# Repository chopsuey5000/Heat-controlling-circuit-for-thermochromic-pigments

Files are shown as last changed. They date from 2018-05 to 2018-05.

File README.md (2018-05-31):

# Heat-controlling-circuit-for-thermochromic-pigments

## Overview
Thermochromic inks are pigments that change color to colorless at certain temperature. There are many different types of thermochromic pigments including textile inks for textile screen printing.

You may use any heat source or your body heat to change the color of thermochromic prints. But also, we can use electricity to heat up certain parts of the fabric to achieve dynamic pattern on fabric.
When large current goes through low resistance conductive material, it emits heat. We can use this method to heat up conductive threads to change colors of the prints.

## Calculations
All conductive threads have different properties, the resistance per meter is different in all of them.
The ideal conductive threads to build a heating source are made of steel or copper.

Some __recommended conductive threads__ like Bekinox stainless steel thread from Bekaert or Copper thread from KarlGrimm.

The __best scenario would be to have a 6-50 Ohm conductive thread with a current of 300-1000 mA__ flowing through it. The time the thermochromic ink takes to change its color is directly proportional to the amount of current. For 300mA it will need more time than for 1000mA.

To __calculate the voltage__ we just need to use ohm's law formula:

Voltage equals Current times Resistance or V = I x R

We know our conductive thread resistance(measured with the multimeter), for example 32 ohm, the current has to be a value from 300mA to 1000mA.

__For 300mA:__

__V = 0,3 * 32 => V = 9,6V__

__For 1000mA:__

__V = 1 * 32 => V = 32V__

## One conductive thread test circuit

### Materials
- Arduino UNO board
- Transistor, TIP122 or IRLZ24N or IRLB8743
- Conductive thread
- Jumper wires
- Protoboard
- Variable DC power supply

### Wiring

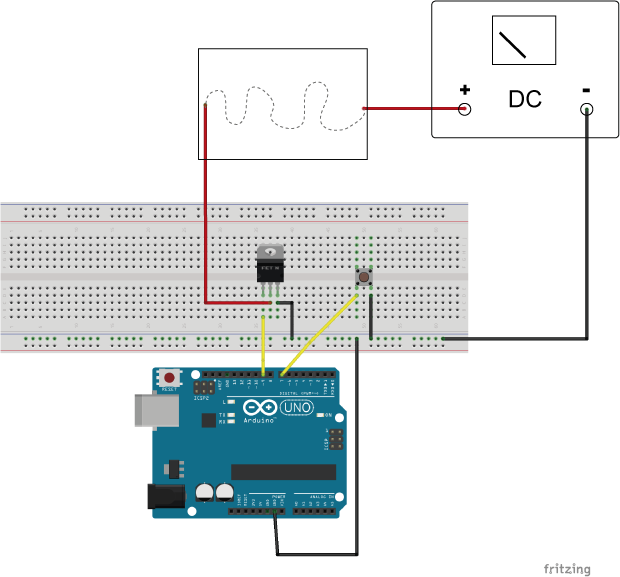
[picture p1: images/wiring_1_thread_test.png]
wiring


### Code - [view](code/_1_thread_test/)

```c++
int btnPin = 7;
int mosfetPin = 9;

void setup() {
  // put your setup code here, to run once:
  pinMode(btnPin,INPUT_PULLUP);
  pinMode(mosfetPin,OUTPUT);
  Serial.begin(9600);
}

void loop() {
  // put your main code here, to run repeatedly:
  int btnState = digitalRead(btnPin); //reads a stores button state
  if(btnState==LOW){
    //button is pressed, so START heating up the conductive thread
    digitalWrite(mosfetPin,HIGH);
  }else{
    //button is released, so STOP heating up the conductive thread
    digitalWrite(mosfetPin,LOW);
  }
}
```

## Multiple conductive threads circuit

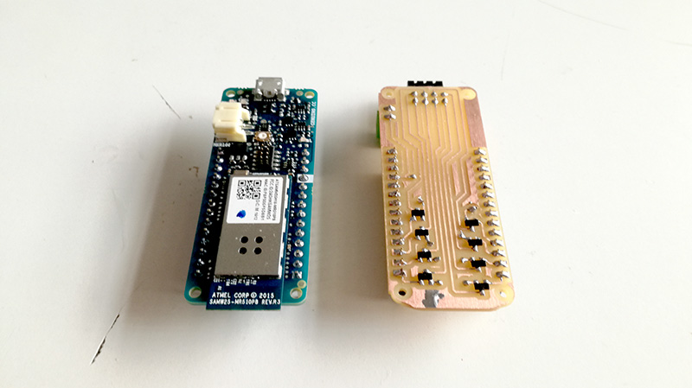
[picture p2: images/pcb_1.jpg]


### Materials
- Arduino MKR1000
- 8x Transistor BC817
- 8x Conductive thread

### PCB

[schematic & board design files](pcb/)

### Code - [view](code/_8_threads_test/)

```c++
#define numStrings 8

int actualString = 0;
int actualTime;
int intervalON = 8000;
int intervalOFF = 10000;
boolean state = 0;

const int pins[numStrings] = {
  9,8,7,6,5,4,3,2
};

const int timeON[numStrings] = {
  7000,9000,10000,10000,5000,6500,8000,10000
};

void setup() {
  // put your setup code here, to run once: 
  Serial.begin(9600);

  for(int i=0;i<numStrings;i++){
    pinMode(pins[i],OUTPUT);
  }

  actualTime = millis();
  
}

void loop() {
  // put your main code here, to run repeatedly:
  if(state==0 && millis()<(actualTime+timeON[actualString]))
  {
    int left = (actualTime+timeON[actualString])-millis();
    Serial.print("ON ");
    Serial.print(" : ");
    Serial.print(actualString);
    Serial.print(" : ");
    Serial.println(left);
    analogWrite(pins[actualString],255);
  }else if (state==0 && millis()>(actualTime+intervalON)){
    actualTime = millis();
    state=1;
  }

  if(state==1 && millis()<(actualTime+intervalOFF))
  {
    int left = (actualTime+intervalOFF)-millis();
    Serial.print("OFF ");
    Serial.print(" : ");
    Serial.print(actualString);
    Serial.print(" : ");
    Serial.println(left);
    analogWrite(pins[actualString],0);
  }else if (state==1 && millis()>(actualTime+intervalOFF)){
    actualTime = millis();
    state=0;
    actualString++;
    if(actualString>=8){
      actualString=0;
      Serial.println("stop");
      delay(10000);
    }
  }
}
```

```## Powering

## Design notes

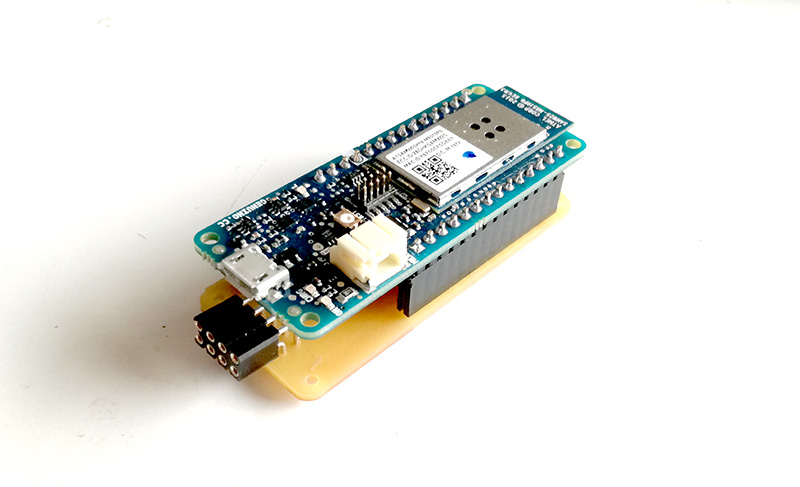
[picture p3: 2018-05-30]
images/pcb_2.jpg

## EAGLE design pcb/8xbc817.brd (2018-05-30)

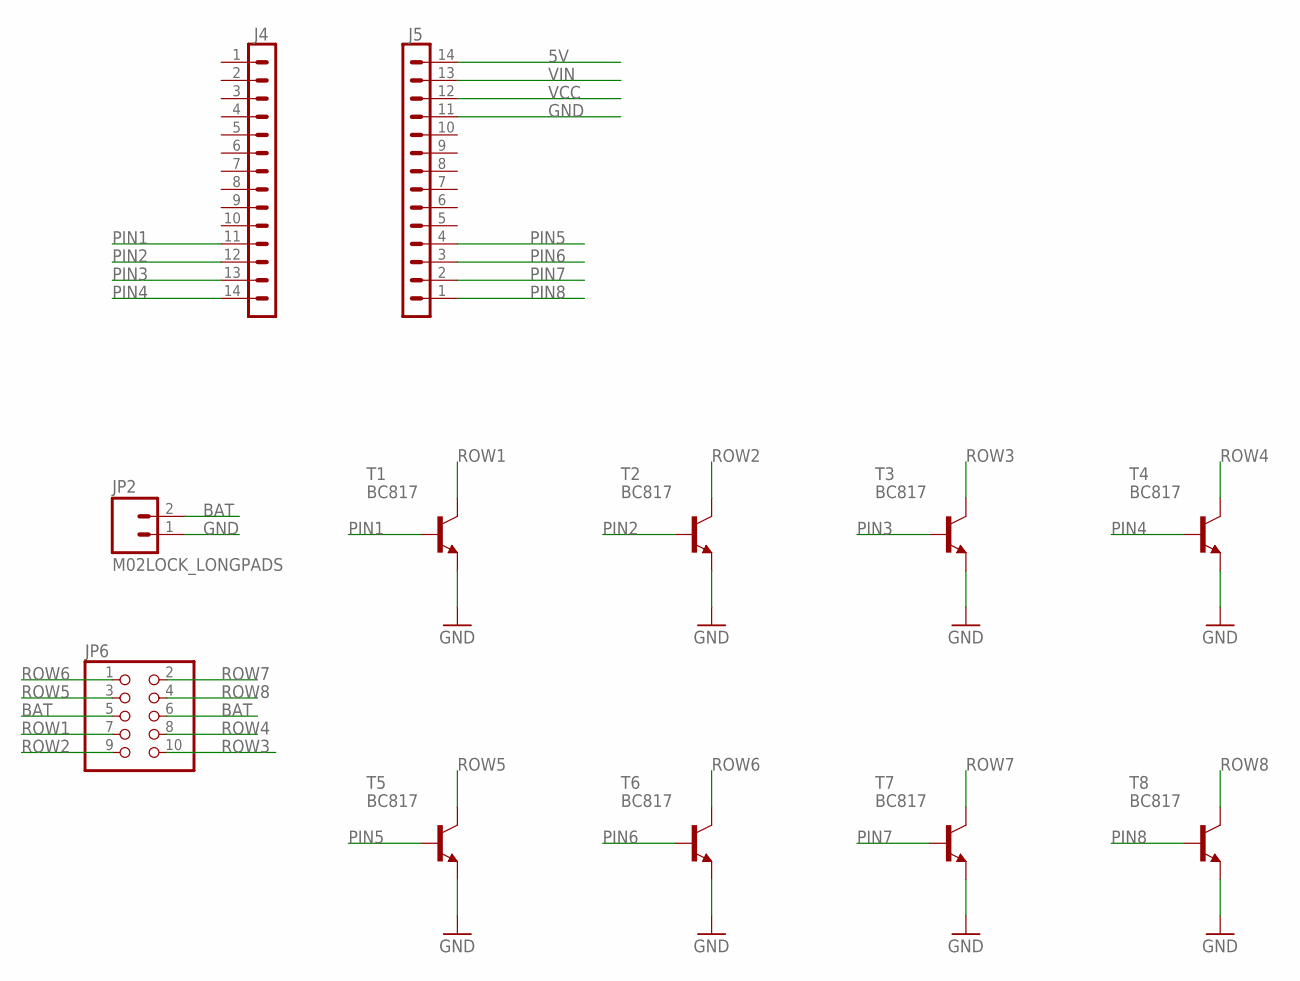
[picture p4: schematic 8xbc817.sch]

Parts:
J4, J5: DNP; STRIP-14-MODULI-A11
JP2: M02LOCK_LONGPADS; 1X02_LOCK_LONGPADS
JP6: PINHD-2X5; 2X05
T1, T2, T3, T4, T5, T6, T7, T8: BC817; SOT23

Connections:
5V: J5.14
BAT: JP2.2, JP6.5, JP6.6
GND: J5.11, JP2.1, T1.2 (E), T2.2 (E), T3.2 (E), T4.2 (E), T5.2 (E), T6.2 (E), T7.2 (E), T8.2 (E)
PIN1: J4.11, T1.1 (B)
PIN2: J4.12, T2.1 (B)
PIN3: J4.13, T3.1 (B)
PIN4: J4.14, T4.1 (B)
PIN5: J5.4, T5.1 (B)
PIN6: J5.3, T6.1 (B)
PIN7: J5.2, T7.1 (B)
PIN8: J5.1, T8.1 (B)
ROW1: JP6.7, T1.3 (C)
ROW2: JP6.9, T2.3 (C)
ROW3: JP6.10, T3.3 (C)
ROW4: JP6.8, T4.3 (C)
ROW5: JP6.3, T5.3 (C)
ROW6: JP6.1, T6.3 (C)
ROW7: JP6.2, T7.3 (C)
ROW8: JP6.4, T8.3 (C)
VCC: J5.12
VIN: J5.13

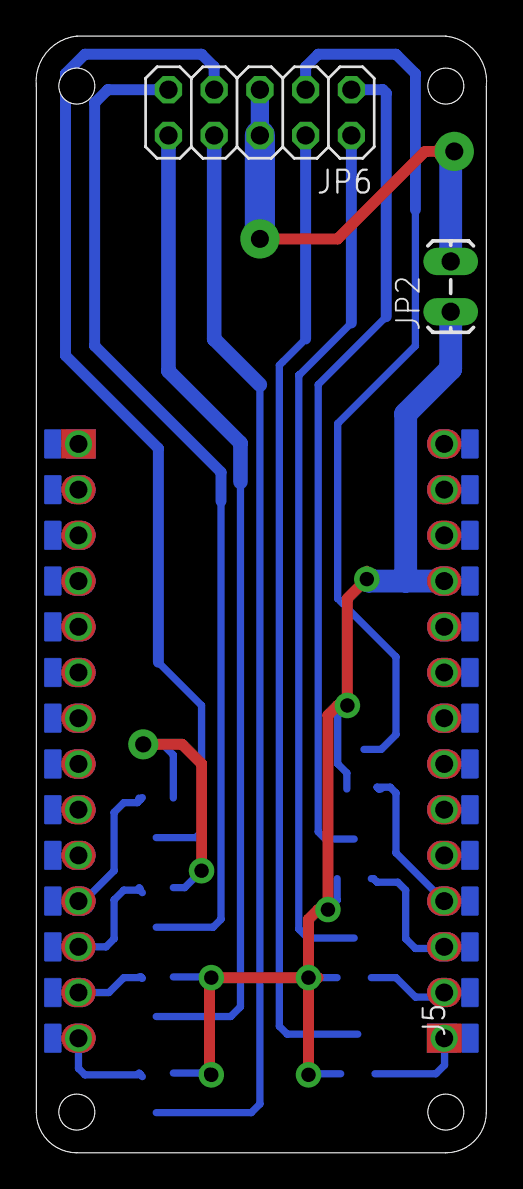
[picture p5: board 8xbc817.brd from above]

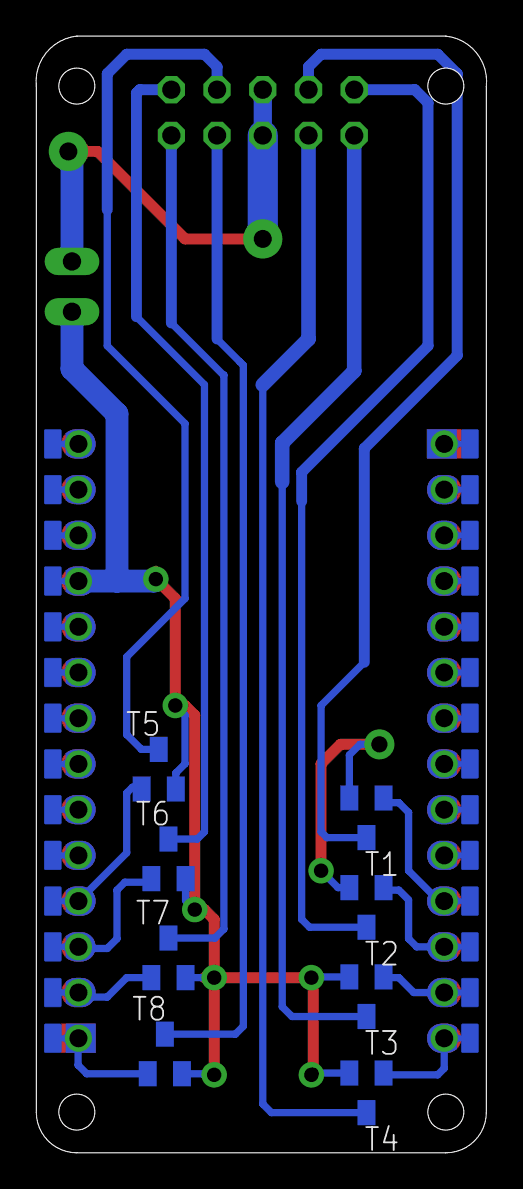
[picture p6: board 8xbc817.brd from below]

Board: 2 copper layers, 25.0 x 62.0 mm, 12 parts (8 on the bottom side), 18 nets.

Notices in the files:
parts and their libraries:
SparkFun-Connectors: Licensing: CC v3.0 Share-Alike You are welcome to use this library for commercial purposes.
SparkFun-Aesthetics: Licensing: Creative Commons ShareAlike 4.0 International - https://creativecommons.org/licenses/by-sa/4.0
